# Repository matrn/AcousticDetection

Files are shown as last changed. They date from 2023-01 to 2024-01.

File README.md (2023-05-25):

# System for Acoustic Detection and Localization Based on Two Microphones
# Systém pro akustickou detekci a lokalizaci založený na dvou mikrofonech

This repository contains the source code, schematic, and PCB layout of a demonstration device designed to detect and locate acoustic impulse events. The device is composed of an ESP32 microcontroller and two MEMS microphones SPH0645LM4H.

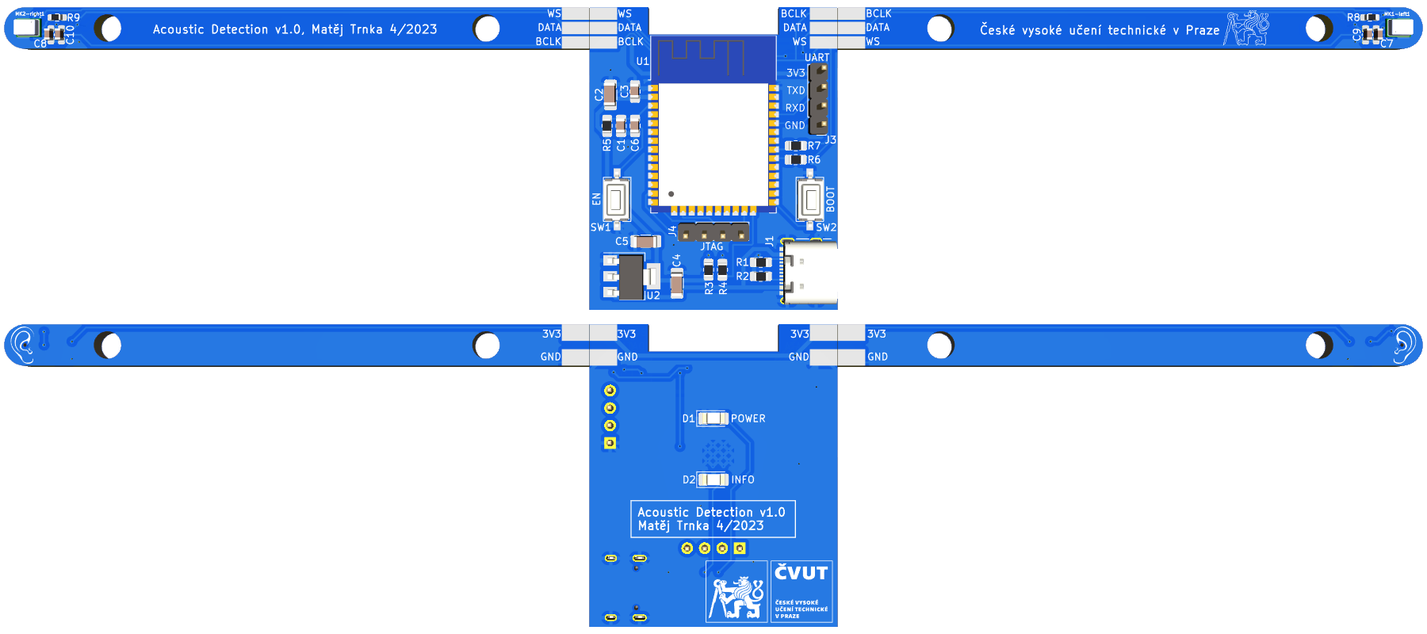
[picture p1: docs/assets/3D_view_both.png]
PCB 3D view

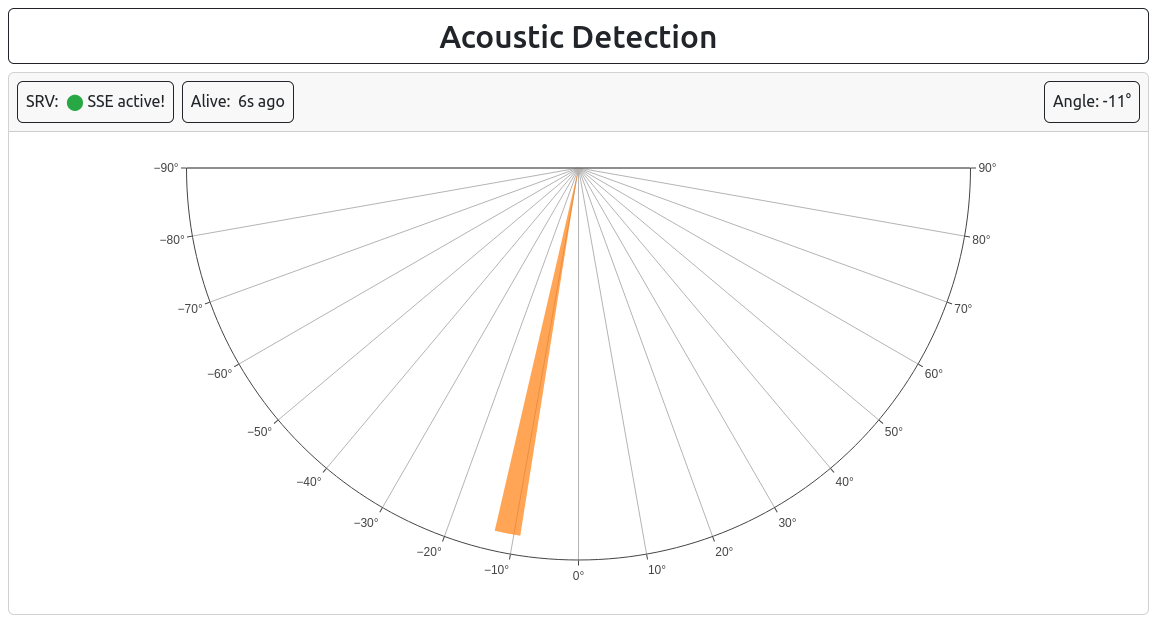
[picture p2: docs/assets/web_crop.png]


## Directories
- `AcousticDetection_HW/` - KiCad schematic & PCB
- `AcousticDetection_SW/` - source code of the ESP32 firmware
- `web` - source code for the ESP32 web page
- `models` - 3D models for 3D printing
- `dsp_toolbox/` - some tools used during development of the signal processing

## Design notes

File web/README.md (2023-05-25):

# ESP32 Web page source code
Script `bundle_all.sh` is automatically called by PlatformIO during FS build.

## Scripts
- python script `bundle.py` takes all files from `src/` dir, if file js Javascript it runs minification and compresses all to the gzip
- bash script `bundle_all.sh` runs `PurgeCSS` to clean unused components from Bootstrap template and then `bundle.py`

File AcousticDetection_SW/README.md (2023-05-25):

# Source code of the AcousticDetection device

The code is written in Arduino framework with the help of PlatformIO platform.

## Code setup
- copy `include/config.hpp.example` to `include/config.hpp` and set required values
- if you want to change distance between microphones, edit `lib/dsp/config.hpp`
- if you want Wi-Fi AP mode instead of station mode, uncomment `#define ENABLE_WIFI_AP` in the `src/main.cpp` file
- to disable OTA (Over the Air) update, comment out `#define ENABLE_OTA`

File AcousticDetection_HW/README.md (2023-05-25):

# KiCad schematic and PCB layout of the AcousticDetection device

PCB 3D view

## Directories
- `lib/` - additional KiCad libraries used for the PCB
- `gerber/` - gerber export ready for production, it containes `single/` version where all three parts are in the same file and `separated/` for three separated gerber files
- `FORMODEL-AcousticDetection_HW/` - copy of this main `AcousticDetection_HW` PCB files, used for the images export into final thesis. Do not use this for production.
- `plots/` - PDF plots of schematic & PCB layout

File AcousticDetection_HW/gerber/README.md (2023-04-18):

# Tutorial
- [https://support.jlcpcb.com/article/194-how-to-generate-gerber-and-drill-files-in-kicad-6](https://support.jlcpcb.com/article/194-how-to-generate-gerber-and-drill-files-in-kicad-6)

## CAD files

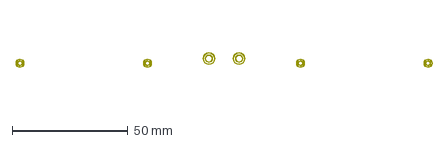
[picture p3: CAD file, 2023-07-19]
models/case/2D.dxf
179.4 x 6.20 mm

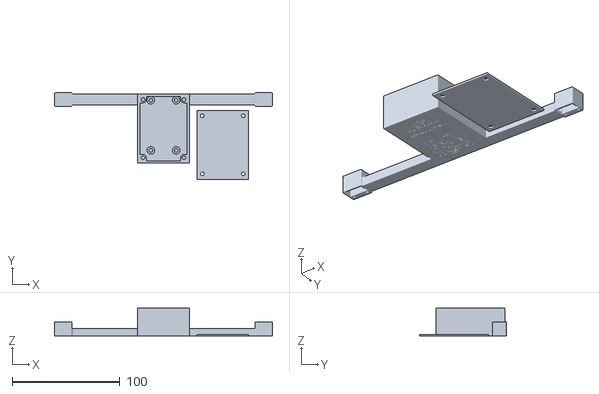
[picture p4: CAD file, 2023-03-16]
models/testing_prototype/AcousticDetectionCase.stl
202.4 x 80.3 x 25.8

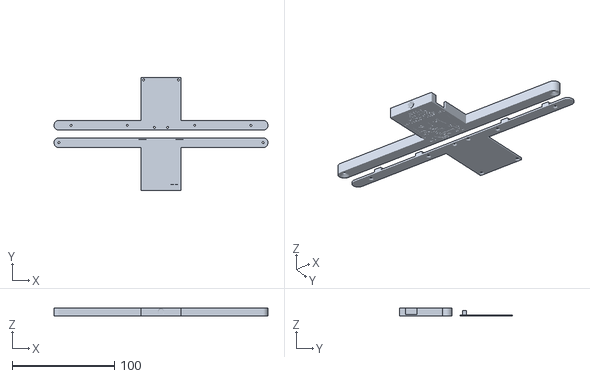
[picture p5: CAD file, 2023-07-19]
models/case/AcousticDetectionCase.stl
209.6 x 111.0 x 7.85

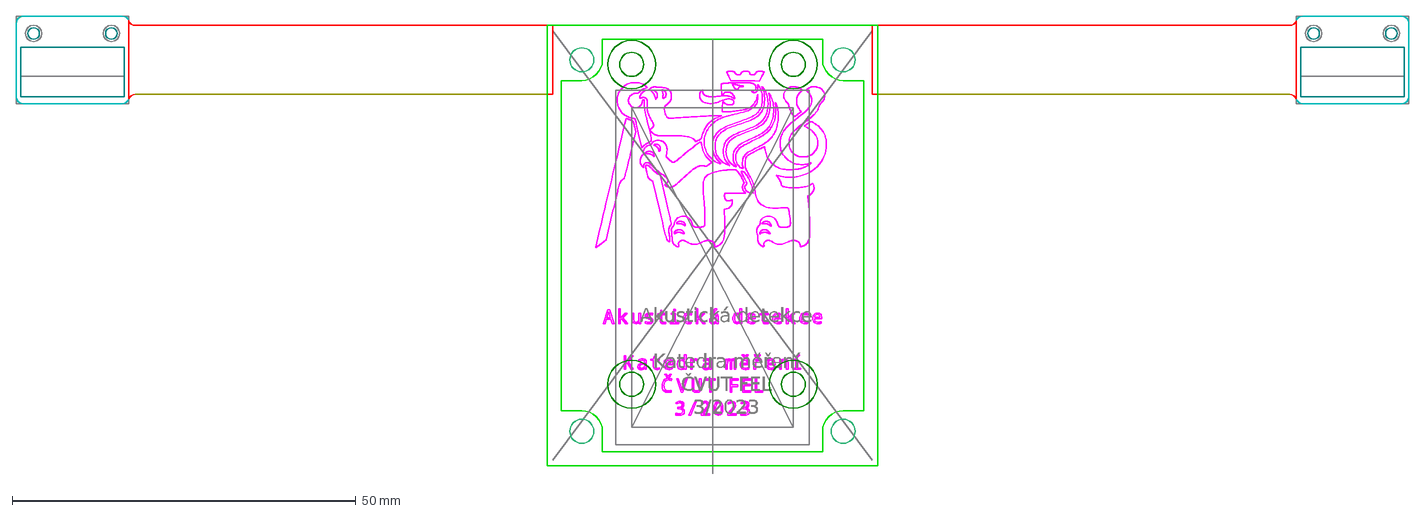
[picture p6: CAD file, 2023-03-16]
models/testing_prototype/2D.dxf
Akustická detekce Katedra měření ČVUT FEL 3/2023

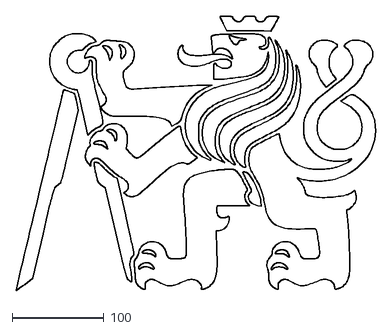
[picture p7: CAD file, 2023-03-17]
models/case/cvut_logo.dxf
393.1 x 299.7

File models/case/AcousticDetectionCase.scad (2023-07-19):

//build = false;
build = true;

$fn = build?200:30;

include <threadlib/threadlib.scad>
UNC_THREAD_SCALE = 1.08;
thread_end_wall_thickness = 0.8;

base_h = 1.6;
logo_h = 0.2;
text_h = 0.2;   //0.4
box_h = 6.25;
arms_h = 4;

solder_pads_h = 1;   // and LEDs

cover_h = 1.2;
cover_pads_h = 4.2;

mic_pos = [100, 19];
mic_hole_r1 = 1;
mic_hole_r2 = 3.6;

cover_holes_h = 1;
cover_holes_r1 = 1;
cover_holes_r2 = 3.9/2;
cover_holes_pos = [
	[88, 19],
	[-88, 19],
	[33, 19],
	[-33, 19],
	[6.5, 21],
	[-6.5, 21],
	[17, -25.5],
	[-17, -25.5]
];


module mic_hole(second=false){
	mp = second?-1:1;
	translate([mp*mic_pos[0], mic_pos[1], base_h/2]) cylinder(base_h, mic_hole_r2, mic_hole_r1, center=true); 
}

module usb_hole(){
	// from bottom 5.5 mm -> from center 16,5 mm
	// from base 3.5
	h = 3.5;
	off = -16.5;
    
	translate([36/2+2/2+1-0.8, off, h]) cube([2, 12, 7], center=true);
}

module box(){
	difference(){
		linear_extrude(box_h) import("2D.dxf", layer="box");
		linear_extrude(box_h+0.1) import("2D.dxf", layer="padded_device");
	}
}

module rotated_tripod_thread(){
	difference(){
		// Most consumer cameras are fitted with 1/4-20 UNC threads (https://en.wikipedia.org/wiki/Tripod_(photography))
		// 20-UN-1/4 = UNC-1/4
		ss = UNC_THREAD_SCALE;
		rotate([90, 0, 0]) scale([ss, ss, ss]) tap("20-UN-1/4", turns=5);
		
		translate([0, 4/2-thread_end_wall_thickness, 0]) cube([10, 4, 10], center = true);
	}
	
}

module box_base(){
difference(){
	union(){	
		difference(){
			linear_extrude(base_h) import("2D.dxf", layer="box");
			translate([0,0,base_h-solder_pads_h]) linear_extrude(solder_pads_h) import("2D.dxf", layer="solder_pads");
			translate([0,0,-0.02]) linear_extrude(logo_h) mirror([1,0,0]) import("2D.dxf", layer="logo");
			translate([0,0,-0.02]) linear_extrude(text_h) mirror([1,0,0]) import("2D.dxf", layer="text");    
		}

		//usb_hole();

		translate([0,0,base_h]){
			difference(){
				box();
				usb_hole();
			}    
			linear_extrude(box_h-0.2) import("2D.dxf", layer="mount");
		}
	}

	translate([0, -22.2, (base_h+box_h)/2]) rotated_tripod_thread();
	mic_hole();
	mic_hole(true);
}
}

module box_cover(){
difference(){
	union(){
		linear_extrude(cover_h) import("2D.dxf", layer="cover");
		translate([0,0,-cover_pads_h]) linear_extrude(cover_pads_h) import("2D.dxf", layer="cover_pads");
	}
	
	for(pos = cover_holes_pos){
		translate(pos) translate([0,0,cover_h-cover_holes_h/2]) cylinder(cover_holes_h, cover_holes_r1, cover_holes_r2, center=true);
	}
}
}

box_base();
//box_cover();

if(build) translate([0, 55, cover_h]) rotate([0,180,180]) box_cover();
else translate([0, 0, base_h+box_h+2]) box_cover();

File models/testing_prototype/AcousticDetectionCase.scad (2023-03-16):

//build = false;
build = true;

$fn = build?200:30;

	

base_h = 0.8;
logo_h = 0.2;
box_h = 25;
esp_h = 10;
mics_h = 12;
mics_cap_h = 0.8;
arms_h = 6;
cover_h = 1.2;

module usb_hole(){
	h = esp_h + 3;
	off = 30.5;
    
	translate([0, off, h]) cube([10, 2, 6], center=true);
}

module cable_hole(){
	l = 171.4;
	d = 4;
	off = 26.8;
	off_z = 2.7;
    translate([0, off, off_z]) rotate([0, 90, 0]) cylinder(h=l, d=d, center = true);
}


difference(){
    linear_extrude(base_h) import("2D.dxf", layer="base");
    translate([0,0,-0.02]) linear_extrude(logo_h) mirror([1,0,0]) import("2D.dxf", layer="logo");
    translate([0,0,-0.05]) linear_extrude(base_h+0.1) import("2D.dxf", layer="mics_holes");
}

//cable_hole();

translate([0,0,base_h]){
    difference()
    {
        linear_extrude(box_h) import("2D.dxf", layer="box");
        usb_hole();
		cable_hole();
    }
    
    linear_extrude(esp_h) import("2D.dxf", layer="esp");
    
    difference(){
        linear_extrude(mics_h) import("2D.dxf", layer="mics_box");
        translate([0,0,-0.05]) linear_extrude(mics_h-mics_cap_h+0.05) import("2D.dxf", layer="mics_holes");
        cable_hole();
    }
    
    difference(){
        linear_extrude(arms_h) import("2D.dxf", layer="arms");
        cable_hole();
    }
}

if(build) translate([55, -15, 0]) linear_extrude(cover_h) import("2D.dxf", layer="cover");
else translate([0, 0, base_h+box_h+2]) linear_extrude(cover_h) import("2D.dxf", layer="cover");

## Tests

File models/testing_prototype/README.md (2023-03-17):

## 3D design problems
- SPH0645 mics (SMD part) collide with design - there should be a small rectangular hole
- ESP32's pin headers are blocked by 2 of 4 cylinders on the back side
- cylinders holes for ESP32 are too big for the M3 screw without a threaded insert
- hole for cables in the arms should be a little bit bigger
- text is not readable - it should be higher and text bigger (size of the CTU logo is fine)

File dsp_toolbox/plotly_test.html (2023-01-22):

## Acoustic Detection

WS: ⬤ WS not loaded Angle: -

Logs

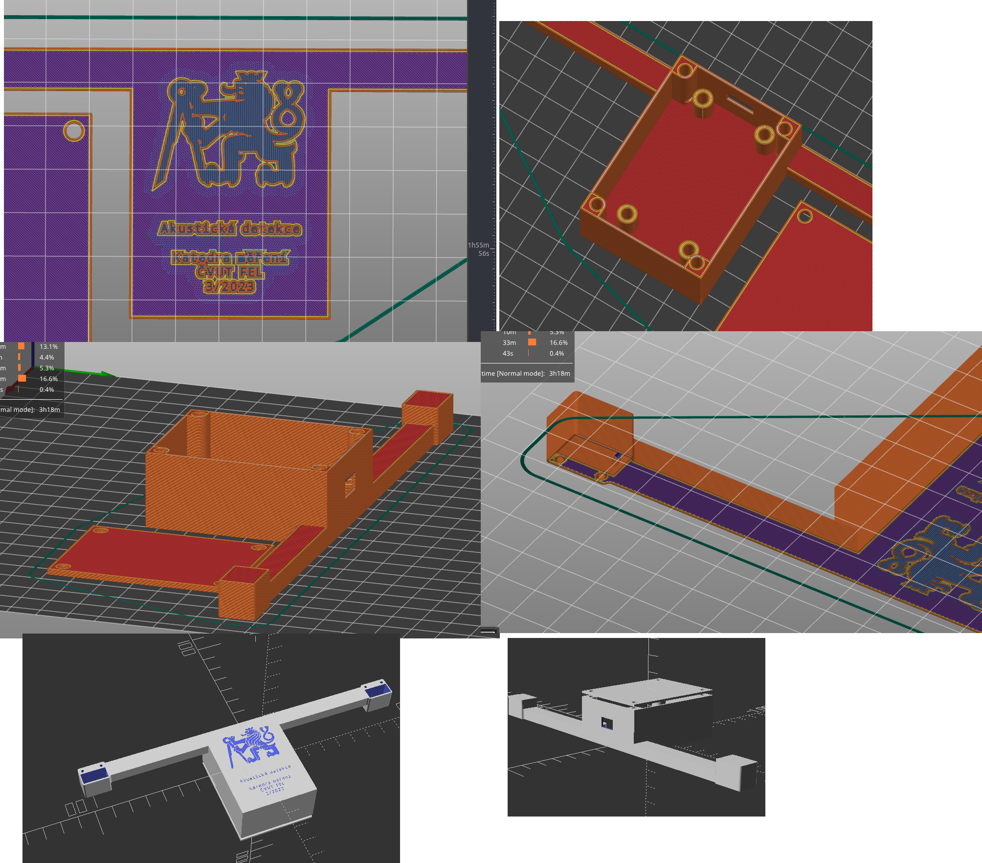
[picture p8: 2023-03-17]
models/testing_prototype/box.png

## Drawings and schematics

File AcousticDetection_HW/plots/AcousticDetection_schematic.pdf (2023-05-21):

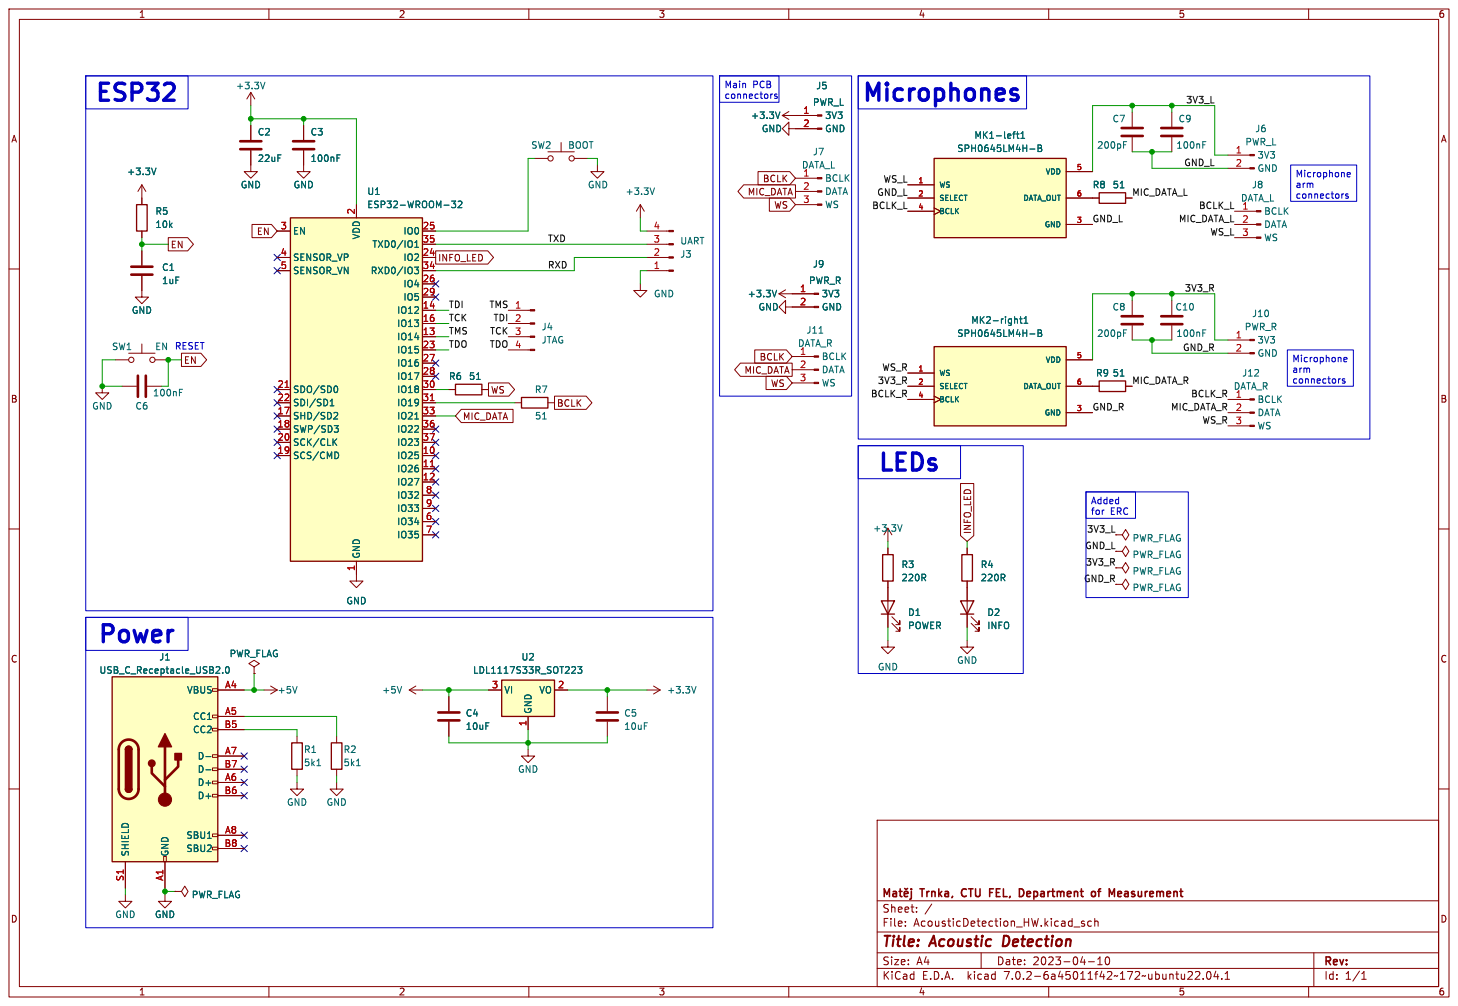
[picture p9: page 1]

2 SCK/CLK 20 SDO/SD0 21 SDI/SD1 22

Id: 1/1 Title: Acoustic Detection

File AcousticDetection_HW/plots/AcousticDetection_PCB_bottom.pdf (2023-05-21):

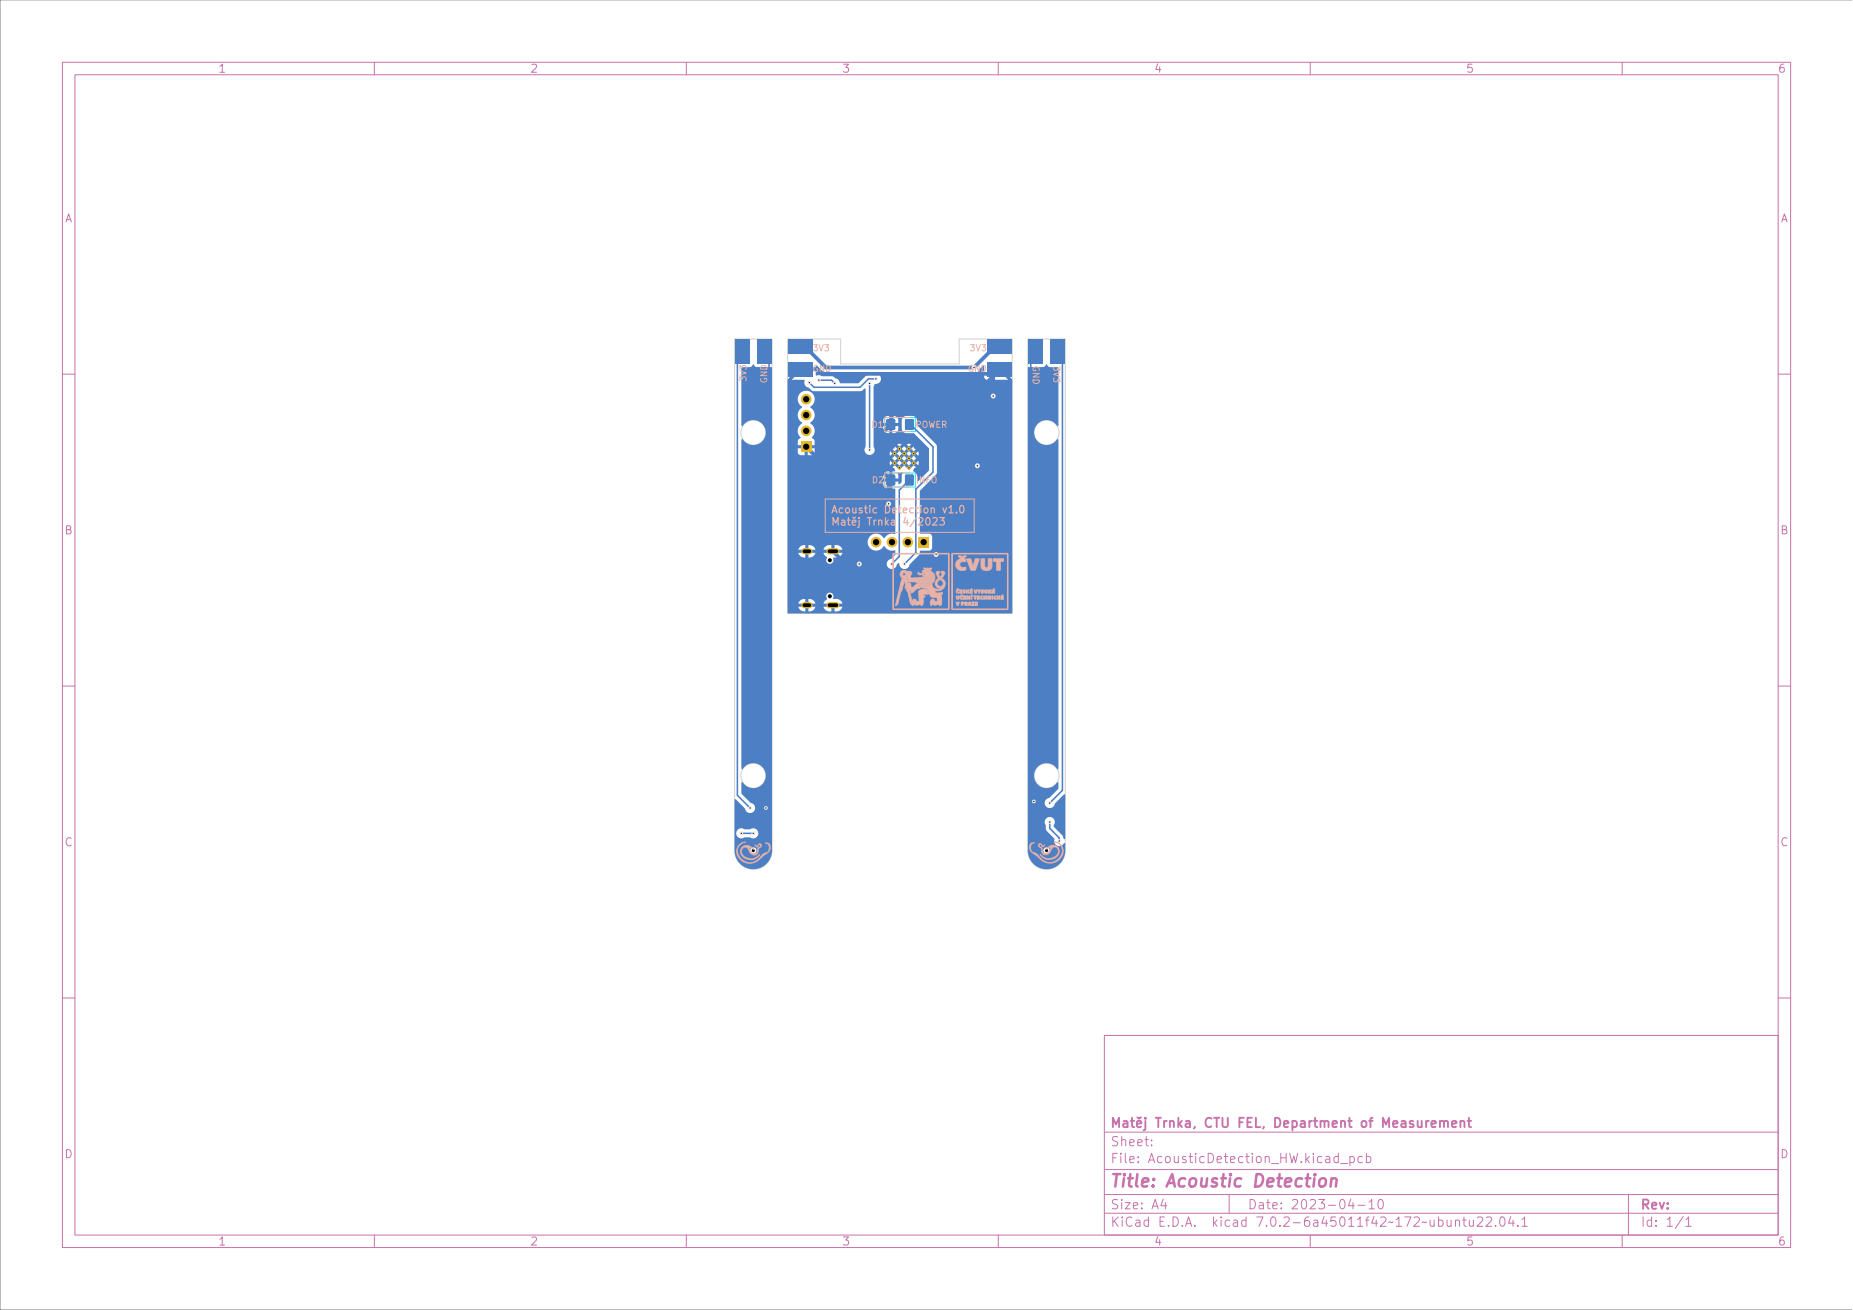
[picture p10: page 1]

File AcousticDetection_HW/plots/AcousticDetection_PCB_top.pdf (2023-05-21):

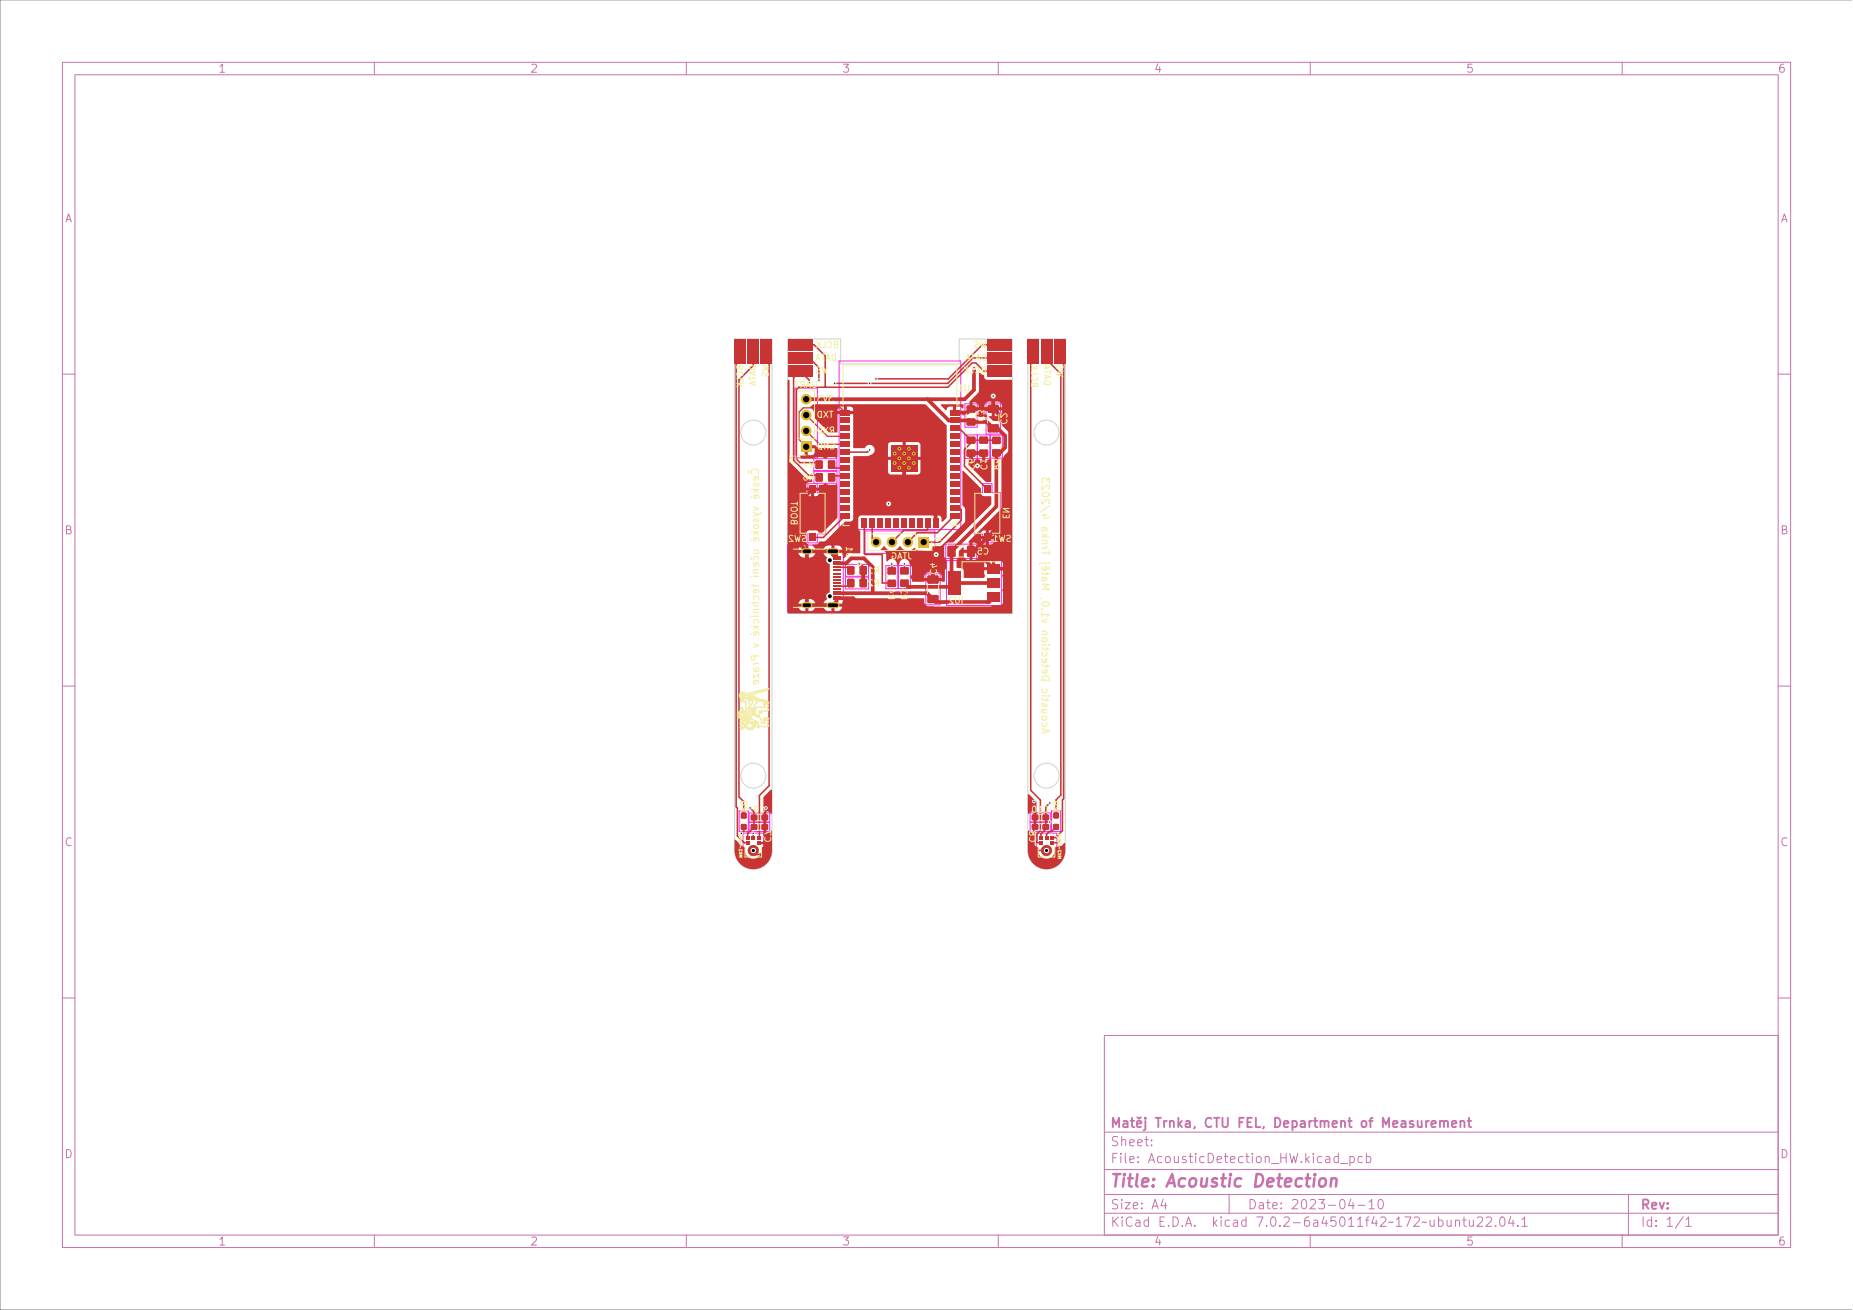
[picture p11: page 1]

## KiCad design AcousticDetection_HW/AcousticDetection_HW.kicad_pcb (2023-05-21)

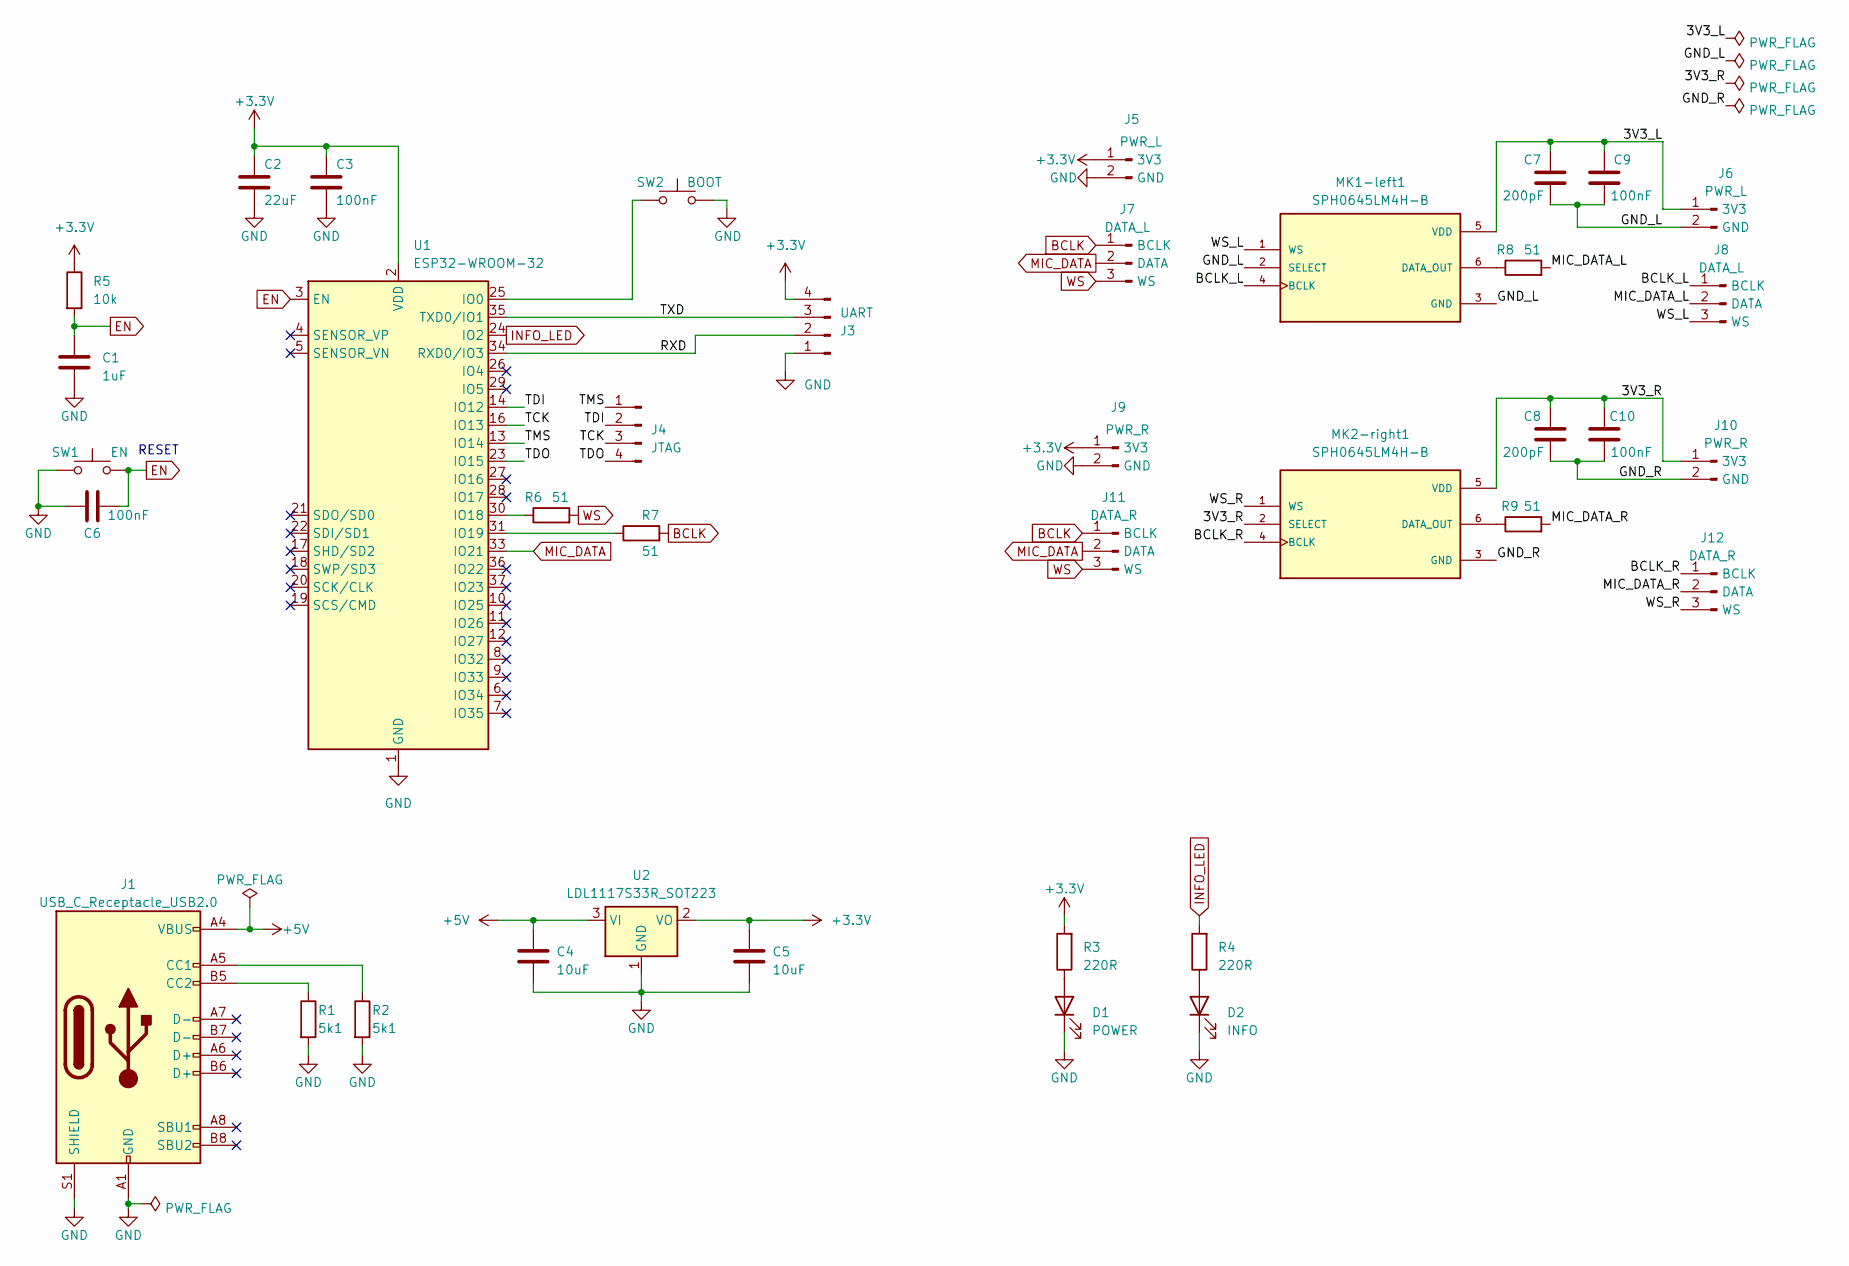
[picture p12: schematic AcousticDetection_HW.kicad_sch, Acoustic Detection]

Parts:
C1: 1uF; C_0805_2012Metric_Pad1.18x1.45mm_HandSolder
C2: 22uF; C_1206_3216Metric_Pad1.33x1.80mm_HandSolder
C3, C6: 100nF; C_0805_2012Metric_Pad1.18x1.45mm_HandSolder
C4, C5: 10uF; C_1206_3216Metric_Pad1.33x1.80mm_HandSolder
C7, C8: 200pF; C_0603_1608Metric_Pad1.08x0.95mm_HandSolder
C9, C10: 100nF; C_0603_1608Metric_Pad1.08x0.95mm_HandSolder
D1: POWER; LED_1206_3216Metric_Pad1.42x1.75mm_HandSolder
D2: INFO; LED_1206_3216Metric_Pad1.42x1.75mm_HandSolder
J1: USB_C_Receptacle_USB2.0; USB_C_Receptacle_GCT_USB4105-xx-A_16P_TopMnt_Horizontal
J3: UART; PinHeader_1x04_P2.54mm_Vertical
J4: JTAG; PinHeader_1x04_P2.54mm_Vertical
J5, J6: PWR_L; PowerConnector
J7, J8: DATA_L; DataConnector
J9, J10: PWR_R; PowerConnector
J11, J12: DATA_R; DataConnector
MK1-left1, MK2-right1: SPH0645LM4H-B; MIC_SPH0645LM4H-B
R1, R2: 5k1; R_0805_2012Metric_Pad1.20x1.40mm_HandSolder
R3, R4: 220R; R_0805_2012Metric_Pad1.20x1.40mm_HandSolder
R5: 10k; R_0805_2012Metric_Pad1.20x1.40mm_HandSolder
R6, R7: 51; R_0805_2012Metric_Pad1.20x1.40mm_HandSolder
R8, R9: 51; R_0603_1608Metric_Pad0.98x0.95mm_HandSolder
SW1: EN; SW_Tactile_SPST_NO_Straight_CK_PTS636Sx25SMTRLFS
SW2: BOOT; SW_Tactile_SPST_NO_Straight_CK_PTS636Sx25SMTRLFS
U1: ESP32-WROOM-32
U2: LDL1117S33R_SOT223; SOT-223-3_TabPin2

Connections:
+3.3V: C2.2, C3.2, C5.1, J3.4, J5.1 (3V3), J9.1 (3V3), R3.2, R5.1, U1.2 (VDD), U2.2 (VO)
+5V: C4.1, J1.A4 (VBUS), J1.A9 (VBUS), J1.B4 (VBUS), J1.B9 (VBUS), U2.3 (VI)
/3V3_L: C7.2, C9.2, J6.1 (3V3), MK1-left1.5 (VDD)
/3V3_R: C8.2, C10.2, J10.1 (3V3), MK2-right1.2 (SELECT), MK2-right1.5 (VDD)
/BCLK_L: J8.1 (BCLK), MK1-left1.4 (BCLK)
/BCLK_R: J12.1 (BCLK), MK2-right1.4 (BCLK)
/GND_L: C7.1, C9.1, J6.2 (GND), MK1-left1.2 (SELECT), MK1-left1.3 (GND)
/GND_R: C8.1, C10.1, J10.2 (GND), MK2-right1.3 (GND)
/MIC_DATA_L: J8.2 (DATA), R8.2
/MIC_DATA_R: J12.2 (DATA), R9.2
/RXD: J3.2, U1.34 (RXD0/IO3)
/TCK: J4.3, U1.16 (IO13)
/TDI: J4.2, U1.14 (IO12)
/TDO: J4.4, U1.23 (IO15)
/TMS: J4.1, U1.13 (IO14)
/TXD: J3.3, U1.35 (TXD0/IO1)
/WS_L: J8.3 (WS), MK1-left1.1 (WS)
/WS_R: J12.3 (WS), MK2-right1.1 (WS)
BCLK: J7.1 (BCLK), J11.1 (BCLK), R7.2
EN: C1.2, C6.2, R5.2, SW1.2, U1.3 (EN)
GND: C1.1, C2.1, C3.1, C4.2, C5.2, C6.1, D1.1 (K), D2.1 (K), J1.A1 (GND), J1.A12 (GND), J1.B1 (GND), J1.B12 (GND), J1.S1 (SHIELD), J3.1, J5.2 (GND), J9.2 (GND), R1.2, R2.2, SW1.1, SW2.2, U1.1 (GND), U1.15 (GND), U1.38 (GND), U1.39 (GND), U2.1 (GND)
INFO_LED: R4.2, U1.24 (IO2)
MIC_DATA: J7.2 (DATA), J11.2 (DATA), U1.33 (IO21)
unnamed: D1.2 (A), R3.1
unnamed: D2.2 (A), R4.1
unnamed: J1.A5 (CC1), R2.1
unnamed: J1.B5 (CC2), R1.1
unnamed: MK1-left1.6 (DATA_OUT), R8.1
unnamed: MK2-right1.6 (DATA_OUT), R9.1
unnamed: SW2.1, U1.25 (IO0)
unnamed: R6.1, U1.30 (IO18)
unnamed: R7.1, U1.31 (IO19)
WS: J7.3 (WS), J11.3 (WS), R6.2

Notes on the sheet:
RESET

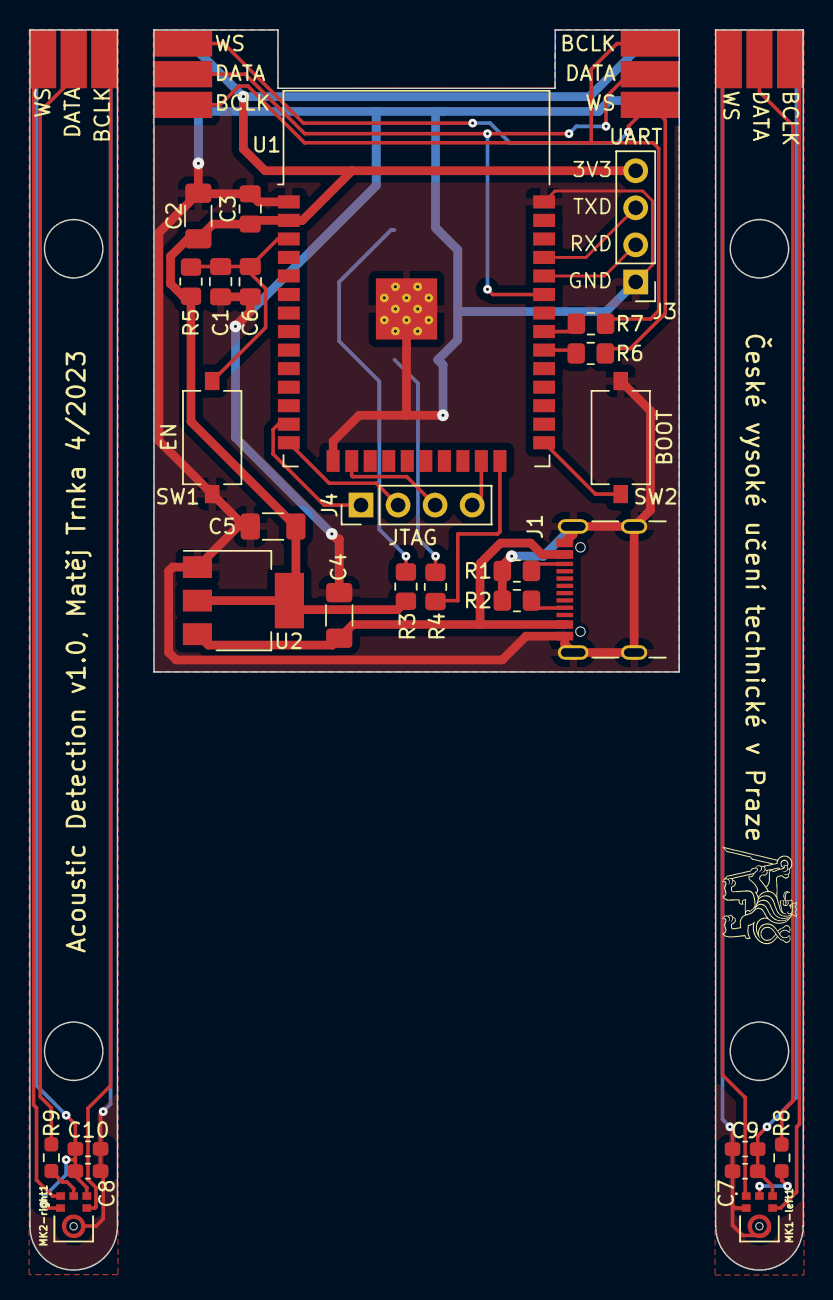
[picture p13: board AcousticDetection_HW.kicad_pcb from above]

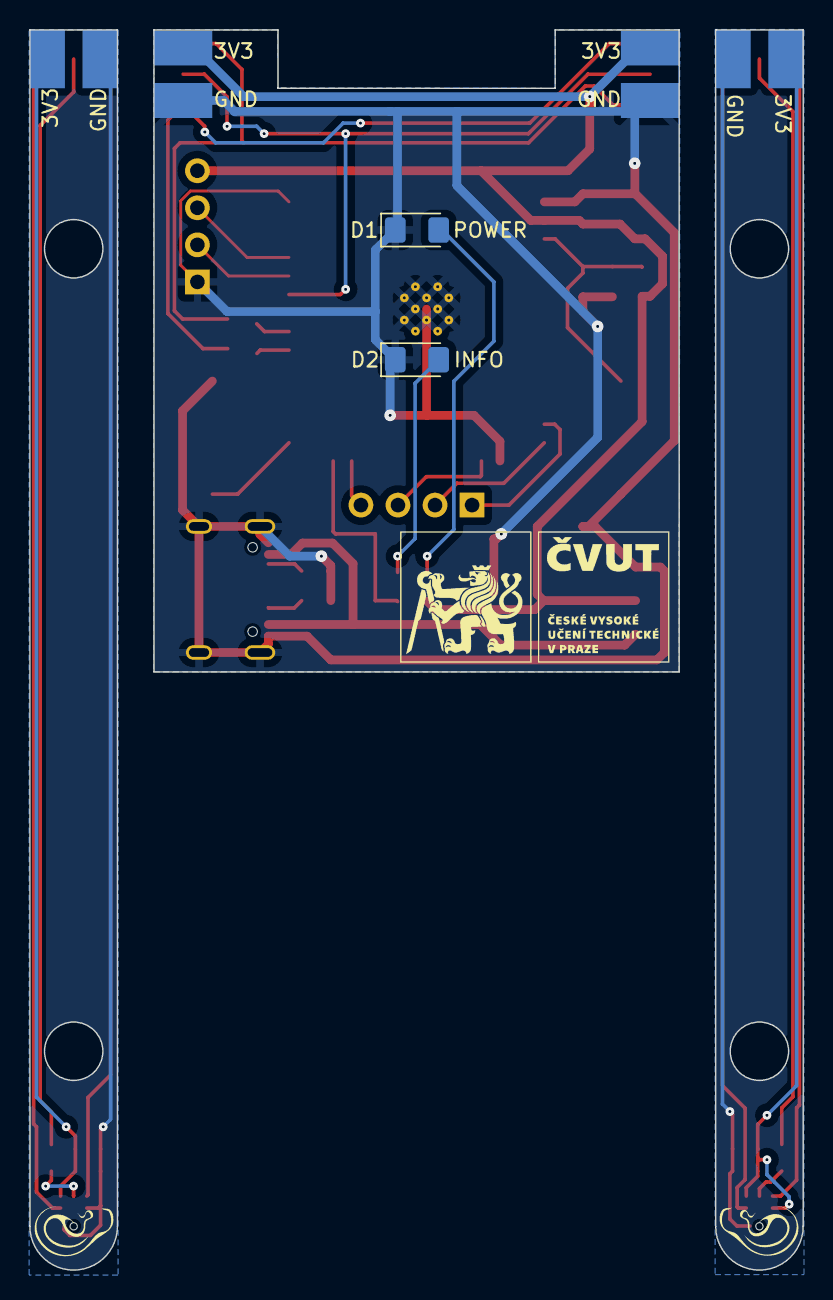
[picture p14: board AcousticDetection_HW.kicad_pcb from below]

Board: 2 copper layers, 53.0 x 85.0 mm, 38 parts (6 on the bottom side), 33 nets.

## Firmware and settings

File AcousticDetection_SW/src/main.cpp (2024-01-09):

#include <Arduino.h>
#include <AsyncTCP.h>
#include <EEPROM.h>
#include <ESPAsyncWebServer.h>
#include <ESPmDNS.h>
#include <FS.h>
#include <SPIFFS.h>
#include <SPIFFSEditor.h>
#include <WiFi.h>

#include "../include/circular_buffer.hpp"
#include "../include/config.hpp"
#include "../lib/dsp/dsp.hpp"
#include "../lib/i2s_mic/mic.hpp"


// ---------- SETTINGS ---------- //
// #define ENABLE_WS    // WebSockets
#define ENABLE_SSE	// Server Sent Events
// #define ENABLE_SSE_CORS_HEADER   // used when you want to request server from different url (for example if you open index.html file in your browser)

#define ENABLE_WIFI_AP	// WIFI_STA otherwise
/* settings bellow are not recommended because it cause performance problems */
// #define ENABLE_WIFI_AP_404_REDIRECT
// #define ENABLE_WIFI_AP_DNS
// #define ENABLE_WIFI_AP_CAPTIVE_PORTAL   // not recommended

#define ENABLE_OTA

// #define AUDIO_CAPTURE_SERVER_ENABLED   // if enabled, ESP32 sends audio samples to the server specified in AUDIO_CAPTURE_SERVER_URL via HTTP
// ------------------------------ //
#define LAST_CAPTURE_TIME_THRESHOLD 100	// 100ms - minimal delay between acoustic event detections - it's used to prevent detection of sound reflections (echo supression)



#ifdef AUDIO_CAPTURE_SERVER_ENABLED
	// The problem is that parts of the audio stream are missing, probably because of the too long data sending process
	#define AUDIO_CAPTURE_SERVER_URL "http://192.168.0.100:5005/i2s_samples"  //"http://192.168.26.92:5005/i2s_samples"
	// #define AUDIO_CAPTURE_SERVER_URL "http://10.42.0.1:5005/i2s_samples"
	#define SAMPLES_PER_REQ 1024 * 50
	#include <HTTPClient.h>
	WiFiClient wifiClient;
	HTTPClient httpClient;
	uint8_t *data_for_send;
#endif


#ifdef ENABLE_WIFI_AP
	#include <DNSServer.h>
	DNSServer dnsServer;
	const IPAddress AP_local_ip(192, 168, 1, 1);
	const IPAddress AP_gateway(192, 168, 1, 1);
	const IPAddress AP_subnet(255, 255, 255, 0);

	#ifdef ENABLE_WIFI_AP_CAPTIVE_PORTAL
		class CaptiveRequestHandler : public AsyncWebHandler {
		public:
			CaptiveRequestHandler() {}
			virtual ~CaptiveRequestHandler() {}

			bool canHandle(AsyncWebServerRequest *request) {
				// request->addInterestingHeader("ANY");
				return true;
			}

			void handleRequest(AsyncWebServerRequest *request) {
				Serial.printf("Client was trying to reach: http://%s%s\n", request->host().c_str(), request->url().c_str());
				AsyncWebServerResponse *response = request->beginResponse(302);
				response->addHeader("Location", "http://" + WiFi.softAPIP().toString());
				return request->send(response);
			}
		};
	#endif
#endif

#ifdef ENABLE_OTA
	#include <ArduinoOTA.h>
#endif


#define CORR_SIZE correlation_window_samples_num
CircularBuffer<audio_sample_t, CORR_SIZE> x1;
CircularBuffer<audio_sample_t, CORR_SIZE> x2;

LRMics mics(I2S_NUM_0);

TaskHandle_t dsp_task;
DSP dsp;

OnsetDetector od1;
OnsetDetector od2;



AsyncWebServer server(80);
#ifdef ENABLE_WS
	AsyncWebSocket ws("/ws");
#endif
#ifdef ENABLE_SSE
	AsyncEventSource events("/events");
	#define SSE_SEND_ALIVE_MSG_TIME 8 * 1000  // 8 seconds
	unsigned long last_sse_alive_msg_time = 0;

	void sse_send_alive_msg() {
		events.send(String(millis()).c_str(), "alive");
	}
#endif



void send_angle(int angle, int error) {
	/*
		@angle - angle in range [0, 180]
		@error - uncertainty of angle in range [0, 10] - on web, width will be width=2*error
	*/
	char str[12];
	sprintf(str, "%d;%d", angle, error);
	#ifdef ENABLE_WS
		ws.textAll(str);
	#endif
	#ifdef ENABLE_SSE
		events.send(str, "angle");
	#endif
}

void dsp_func(void *param) {
	Serial.printf("DSP running on core: %d\n", xPortGetCoreID());
	LRMics *sampler = (LRMics *)(param);

	#ifndef AUDIO_CAPTURE_SERVER_ENABLED
		int capture_number_of_samples = 0;
		bool capture_started = false;

		unsigned long last_capture = 0;
	#endif

	while (true) {
		// mics.read_and_print();
		// continue;

		#ifdef AUDIO_CAPTURE_SERVER_ENABLED
			int sampled = 0;
			int ppp = 0;
			while (sampled < SAMPLES_PER_REQ) {
				int count = sampler->read(true);  //[](audio_sample_t left, audio_sample_t right){

				Serial.printf("%d, %d\n", count, sampled);
				// Serial.println("-------LEFT-------");
				// for(int i = 0; i < count; i ++) Serial.printf("%d,", sampler->left_channel_data[i]);
				// Serial.println("------------------");

				// Serial.println("-------RIGHT-------");
				// for(int i = 0; i < count; i ++) Serial.printf("%d,", sampler->right_channel_data[i]);
				// Serial.println("-------------------");

				memcpy(data_for_send + sampled * sizeof(int16_t), sampler->data, count * sizeof(int16_t));
				sampled += count;

				if (ppp == 5) httpClient.begin(wifiClient, AUDIO_CAPTURE_SERVER_URL);
				if (ppp == 6) httpClient.addHeader("content-type", "application/octet-stream");
				ppp++;
			}

			digitalWrite(LED_BUILTIN, HIGH);
			httpClient.POST(data_for_send, sampled * sizeof(int16_t));
			httpClient.end();
			digitalWrite(LED_BUILTIN, LOW);
			// free(data);
		#else

			int count = sampler->read();  //[](audio_sample_t left, audio_sample_t right){

			for (int i = 0; i < count; i++) {
				audio_sample_t left = sampler->data[i];
				audio_sample_t right = sampler->data[++i];

				// OnSet detection with acoustic echo supression using time delay 100ms (LAST_CAPTURE_TIME_THRESHOLD)
				if (od1.detect(left) && od2.detect(right) && capture_started == false && millis() - last_capture > LAST_CAPTURE_TIME_THRESHOLD) {
					Serial.println("Capture started");
					capture_started = true;
				}

				if (capture_started) {
					/*
						Capture is currently implemented using Circular Buffer because it was used in the past but normal array would be little bit more efficient
					*/
					x1.push(left);
					x2.push(right);
				}

				if (capture_started && ++capture_number_of_samples >= CORR_SIZE) {
					// audio samples capture process is done
					Serial.println("START PROCESSING");
					capture_started = false;
					capture_number_of_samples = 0;
					last_capture = millis();

					xcorr_result_t xcorr_peak;
					bool xcorr_peak_found = dsp.xcorr_max<CircularBuffer<audio_sample_t, CORR_SIZE> >(x1, x2, xcorr_peak, CORR_SIZE, max_shift_samples_num + 1, true, true, true);

					if (xcorr_peak_found) {
						digitalWrite(LED_BUILTIN, HIGH);
						int Nshift = xcorr_peak.max_pos;

						if (xcorr_peak.interpolated_max_pos > Nshift + 1 || xcorr_peak.interpolated_max_pos < Nshift - 1) {
							// this should never happen but added just to be sure
							Serial.printf("ERROR: interpolation %f is outside of %d+(-1,1) range", xcorr_peak.interpolated_max_pos, Nshift);
							xcorr_peak.interpolated_max_pos = Nshift;
						}

						double tau = xcorr_peak.interpolated_max_pos * (1. / I2S_SAMPLE_RATE);
						if (-maxN <= Nshift && Nshift <= maxN) {
							// we use interpolated max_pos for angle calculation and normal for error calculation
							int angle = dsp.rad2deg(dsp.theta_from_tau(tau)) + 0.5;
							int error = dsp.rad2deg(dsp.theta_error(Nshift)) + 0.5;

							Serial.printf("Before interpolation: %d, after: %f\n", xcorr_peak.max_pos, xcorr_peak.interpolated_max_pos);
							Serial.printf("N: %d, max: %f, tau: %f s, angle: %d +- %d\n", Nshift, xcorr_peak.max_Rx, tau, angle, error);

							send_angle(angle, error);
						} else {
							// we ignore peaks outside of Nmax interval, CCF is computed on the interval [-Nmax-1, Nmax+1] to save operations
							Serial.printf("XCORR - shift too big: N: %d, max: %f, tau: %f s\n", Nshift, xcorr_peak.max_Rx, tau);
						}
						digitalWrite(LED_BUILTIN, LOW);
					}
				}
			}
		#endif
	}
}

#ifdef ENABLE_WS
	void onWsEvent(AsyncWebSocket *server, AsyncWebSocketClient *client, AwsEventType type, void *arg, uint8_t *data, size_t len) {
		if (type == WS_EVT_CONNECT) {
			Serial.printf("ws[%s][%u] connect\n", server->url(), client->id());
			client->printf("Hello Client %u :)", client->id());
			client->ping();
		} else if (type == WS_EVT_DISCONNECT) {
			Serial.printf("ws[%s][%u] disconnect\n", server->url(), client->id());
		} else if (type == WS_EVT_ERROR) {
			Serial.printf("ws[%s][%u] error(%u): %s\n", server->url(), client->id(), *((uint16_t *)arg), (char *)data);
		} else if (type == WS_EVT_PONG) {
			Serial.printf("ws[%s][%u] pong[%u]: %s\n", server->url(), client->id(), len, (len) ? (char *)data : "");
		} else if (type == WS_EVT_DATA) {
		}
	}
#endif


#define ENABLE_EEPROM_THRESHOLD

#ifdef ENABLE_EEPROM_THRESHOLD
	#define EEPROM_SIZE 2

	union uint16_t_conv {
		char b[2];
		uint16_t val;
	};
	uint16_t get_OD_threshold_from_EEPROM() {
		union uint16_t_conv data;
		data.b[0] = EEPROM.read(0);
		data.b[1] = EEPROM.read(1);
		return data.val;
	}

	void set_OD_threshold_to_EEPROM(uint16_t val) {
		od1.set_threshold(val);
		od2.set_threshold(val);

		union uint16_t_conv data;
		data.val = val;
		EEPROM.write(0, data.b[0]);
		EEPROM.write(1, data.b[1]);
		EEPROM.commit();
	}
#endif


void setup() {
	pinMode(LED_BUILTIN, OUTPUT);
	digitalWrite(LED_BUILTIN, HIGH);
	Serial.begin(115200);

	#ifdef ENABLE_EEPROM_THRESHOLD
		EEPROM.begin(EEPROM_SIZE);
		uint16_t OD_threshold = get_OD_threshold_from_EEPROM();
		if(OD_threshold < std::numeric_limits<std::uint16_t>::max()){
			od1.set_threshold(OD_threshold);
			od2.set_threshold(OD_threshold);
		}
	#endif
	
	#ifndef RELEASE
		Serial.setDebugOutput(true);
	#endif
	Serial.print(F("START, file: " __FILE__ " built on " __DATE__ " " __TIME__));
	#ifdef RELEASE
		Serial.println(" - RELEASE version");
	#else
		Serial.println(" - DEBUG version");
	#endif

	Serial.println("-----------------------------");
	Serial.println("ESP32 Acoustic Detection v1.0");
	Serial.println("-----------------------------");

	Serial.printf("xcorr window size: %d\n", CORR_SIZE);
	Serial.printf("fs: %d, mics d: %f, max N: %d\n", I2S_SAMPLE_RATE, MICS_DISTANCE, maxN);
	Serial.printf("setup running on core: %d\n", xPortGetCoreID());
	mics.init();

	#ifdef AUDIO_CAPTURE_SERVER_ENABLED
		data_for_send = (uint8_t *)malloc(SAMPLES_PER_REQ * sizeof(int16_t));
	#endif

	// Serial.println(ESP.getFreeHeap());
	// for(int i = 0; i < 2; i ++){
	// 	data_for_send.push((uint8_t*)malloc(SAMPLES_PER_REQ*sizeof(int16_t)));
	// }
	// Serial.println(ESP.getFreeHeap());
	// auto start = micros();
	// for(int i = 0; i < 100; i ++){
	// 	correlation(x1, x2, CORR_SIZE, max_shift_samples_num);
	// }
	// auto end = micros();
	// Serial.printf("Correlation time: %f us\n", (end-start)/100.);
	// while(1);
	/* Core where the task should run */

	#ifdef ENABLE_WIFI_AP
		// docs: https://espressif-docs.readthedocs-hosted.com/projects/arduino-esp32/en/latest/api/wifi.html
		Serial.println("---------- AP mode ----------");
		Serial.println(String("AP creation: ") + (WiFi.softAP(wifi_ap_ssid, wifi_ap_pass, 6, 0, 4) ? "true" : "false"));
		Serial.println(String("AP config: ") + (WiFi.softAPConfig(AP_local_ip, AP_gateway, AP_subnet) ? "true" : "false"));
		Serial.println("-----------------------------");
	#else
		Serial.println("---------- STA mode ----------");
		Serial.printf("Connecting to: %s\n", wifi_ssid);
		WiFi.mode(WIFI_STA);
		WiFi.begin(wifi_ssid, wifi_password);
		for (int i = 0; i < 3; i++) {
			if (WiFi.waitForConnectResult() == WL_CONNECTED) break;
			Serial.print(".");
		}
		if (WiFi.waitForConnectResult() != WL_CONNECTED) {
			Serial.println("Connection Failed! Rebooting...");
			delay(1000);
			ESP.restart();
		}
		WiFi.hostname(hostname);
		Serial.printf("Connected, ip: %s\n", WiFi.localIP().toString().c_str());

		MDNS.addService("http", "tcp", 80);
		Serial.println("------------------------------");
	#endif

	#ifdef ENABLE_OTA
		// Send OTA events to the browser
		ArduinoOTA.onStart([]() { events.send("Update Start", "ota"); });
		ArduinoOTA.onEnd([]() { events.send("Update End", "ota"); });
		ArduinoOTA.onProgress([](unsigned int progress, unsigned int total) {
			#ifdef ENABLE_SSE
				// send OTA update progress via SSE
				char p[32];
				sprintf(p, "Progress: %u%%\n", (progress / (total / 100)));
				events.send(p, "ota");
			#endif
		});
		ArduinoOTA.onError([](ota_error_t error) {
			#ifdef ENABLE_SSE
				if (error == OTA_AUTH_ERROR)
					events.send("Auth Failed", "ota");
				else if (error == OTA_BEGIN_ERROR)
					events.send("Begin Failed", "ota");
				else if (error == OTA_CONNECT_ERROR)
					events.send("Connect Failed", "ota");
				else if (error == OTA_RECEIVE_ERROR)
					events.send("Recieve Failed", "ota");
				else if (error == OTA_END_ERROR)
					events.send("End Failed", "ota");
			#endif
		});
		// Port defaults to 3232
		// ArduinoOTA.setPort(ota_port);

		// Hostname defaults to esp3232-[MAC]
		ArduinoOTA.setHostname(hostname);

		// No authentication by default
		ArduinoOTA.setPassword(ota_password);

		ArduinoOTA.begin();
	#endif

	SPIFFS.begin();

	server.on("/heap", HTTP_GET, [](AsyncWebServerRequest *request) {
		request->send(200, "text/plain", String(ESP.getFreeHeap()));
	});

	server.on("/get_threshold", HTTP_GET, [](AsyncWebServerRequest *request) {
		request->send(200, "text/plain", "od1=" + String(od1.get_threshold()) + ", od2=" + String(od2.get_threshold())
		#ifdef ENABLE_EEPROM_THRESHOLD
			+ ", EEPROM=" + String(get_OD_threshold_from_EEPROM())
		#endif
		);
	});

	#ifdef ENABLE_EEPROM_THRESHOLD
	server.on("/set_threshold", HTTP_POST, [](AsyncWebServerRequest *request) {
		// format is th=uint16_t-number
		// use: curl -X POST http://192.168.1.1/set_threshold -d "th=4700"
		if (request->params() == 1) {
			AsyncWebParameter *p = request->getParam(0);
			if (p->isPost() && p->name() == String("th")) {
				set_OD_threshold_to_EEPROM(p->value().toInt());
				request->send(200, "text/plain", "OK: " + String(get_OD_threshold_from_EEPROM()));
			} else
				request->send(400, "text/plain", "bad request, use th=value, passed var:" + p->name());
		}
		request->send(400, "text/plain", "bad request, number of params is not eq to 1, use th=value");
	});
	#endif

	// serverStatic supports gzip automatically
	// for GMT date us bash command: LC_TIME=en_US.utf8 TZ=GMT date
	server.serveStatic("/", SPIFFS, "/").setDefaultFile("index.html").setLastModified("Tue May 23 11:30:37 AM GMT 2023");  //.setCacheControl("max-age=600");   // Cache responses for 10 minutes (600 seconds)

	server.onNotFound([](AsyncWebServerRequest *request) {
		#ifndef RELEASE
			Serial.printf("NOT_FOUND: ");
			if (request->method() == HTTP_GET)
				Serial.printf("GET");
			else if (request->method() == HTTP_POST)
				Serial.printf("POST");
			else if (request->method() == HTTP_DELETE)
				Serial.printf("DELETE");
			else if (request->method() == HTTP_PUT)
				Serial.printf("PUT");
			else if (request->method() == HTTP_PATCH)
				Serial.printf("PATCH");
			else if (request->method() == HTTP_HEAD)
				Serial.printf("HEAD");
			else if (request->method() == HTTP_OPTIONS)
				Serial.printf("OPTIONS");
			else
				Serial.printf("UNKNOWN");
			Serial.printf(" http://%s%s\n", request->host().c_str(), request->url().c_str());

			if (request->contentLength()) {
				Serial.printf("_CONTENT_TYPE: %s\n", request->contentType().c_str());
				Serial.printf("_CONTENT_LENGTH: %u\n", request->contentLength());
			}

			int headers = request->headers();
			int i;
			for (i = 0; i < headers; i++) {
				AsyncWebHeader *h = request->getHeader(i);
				Serial.printf("_HEADER[%s]: %s\n", h->name().c_str(), h->value().c_str());
			}

			int params = request->params();
			for (i = 0; i < params; i++) {
				AsyncWebParameter *p = request->getParam(i);
				if (p->isFile()) {
					Serial.printf("_FILE[%s]: %s, size: %u\n", p->name().c_str(), p->value().c_str(), p->size());
				} else if (p->isPost()) {
					Serial.printf("_POST[%s]: %s\n", p->name().c_str(), p->value().c_str());
				} else {
					Serial.printf("_GET[%s]: %s\n", p->name().c_str(), p->value().c_str());
				}
			}
		#endif

		#ifdef ENABLE_WIFI_AP
		#ifdef ENABLE_WIFI_AP_404_REDIRECT
				if (request->getHeader("host")->value() != WiFi.softAPIP().toString()) {
					Serial.printf("Wrong host http://%s%s\n, redirecting\n", request->host().c_str(), request->url().c_str());
					request->redirect("http://" + WiFi.softAPIP().toString());
				} else {
					request->send(404, "text/plain", "404 Not Found");
				}
		#else
				request->send(404, "text/plain", "404 Not Found");
		#endif
		#else
				request->send(404, "text/plain", "404 Not Found");
		#endif
	});

	#ifdef ENABLE_WS
		ws.onEvent(onWsEvent);
		server.addHandler(&ws);
	#endif

	#ifdef ENABLE_SSE
		#ifdef ENABLE_SSE_CORS_HEADER
			DefaultHeaders::Instance().addHeader("Access-Control-Allow-Origin", "*");
		#endif
		events.onConnect([](AsyncEventSourceClient *client) {
			sse_send_alive_msg();
		});
		server.addHandler(&events);
	#endif

	#ifdef ENABLE_WIFI_AP
		#ifdef ENABLE_WIFI_AP_DNS
			dnsServer.setErrorReplyCode(DNSReplyCode::NoError);
			dnsServer.start(53, "*", WiFi.softAPIP());	// redirect to ESP
		#endif
		#ifdef ENABLE_WIFI_AP_CAPTIVE_PORTAL
			server.addHandler(new CaptiveRequestHandler()).setFilter(ON_AP_FILTER);	 // only when requested from AP
		#endif
	#endif

	server.begin();

	Serial.println("Setup done, starting DSP...");
	xTaskCreatePinnedToCore(
		dsp_func,  /* Function to implement the task */
		"DSP",	   /* Name of the task */
		10000,	   /* Stack size in words */
		&mics,	   /* Task input parameter */
		2,		   /* Priority of the task */
		&dsp_task, /* Task handle. */
		1
	);
	Serial.println("Done!");
	digitalWrite(LED_BUILTIN, LOW);
}

void loop() {
	#ifdef ENABLE_WS
		ws.cleanupClients();
	#endif

	#ifdef ENABLE_OTA
		ArduinoOTA.handle();
	#endif

	#ifdef ENABLE_SSE
		if (millis() - last_sse_alive_msg_time > SSE_SEND_ALIVE_MSG_TIME || millis() < last_sse_alive_msg_time) {
			last_sse_alive_msg_time = millis();
			sse_send_alive_msg();
		}
	#endif

	#ifdef ENABLE_WIFI_AP
	#ifdef ENABLE_WIFI_AP_DNS
		dnsServer.processNextRequest();
	#endif
	#endif
}

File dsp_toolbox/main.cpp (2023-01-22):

#include <cassert>
#include <iostream>
#include <sciplot/sciplot.hpp>
#include <vector>

#include "../AcousticDetection_SW/lib/dsp/dsp.hpp"
#include "src/include/sampler.hpp"



// #define START 177923
// #define END 178159
// #define START 178300
// #define END 178700
// #define START 76650//1000//51147
// #define END   80000//76800//100000 //52843
#define START 0
#define END -1

//#define CORR_SIZE END-START
#define CORR_SIZE correlation_window_samples_num


#define FILENAME "data/r_pos.raw"


#define Z_SIZE 20

int main(){//int argc, char** argv) {
	Sampler sampler;

	CircularBuffer<audio_sample_t, CORR_SIZE> x1;
	CircularBuffer<audio_sample_t, CORR_SIZE> x2;


	CircularBuffer<int16_t, Z_SIZE> x1_z;
	CircularBuffer<int16_t, Z_SIZE> x2_z;

	CircularBuffer<int16_t, 2> x1_drv;
	CircularBuffer<int16_t, 2> x2_drv;

	DSP dsp;

	if(sampler.open(FILENAME) != 0){
		std::cerr << "ERROR starting sampler\n";
		return 1; 
	}

	std::vector<int> sig_n;
	std::vector<audio_sample_t> sig1;
	std::vector<audio_sample_t> sig2;

	std::vector<uint32_t> sig1_energy;
	std::vector<uint32_t> sig2_energy;

	std::vector<double> sig1_mean;
	std::vector<double> sig2_mean;

	std::vector<double> sig1_envelope;
	std::vector<double> sig2_envelope;
	
	std::vector<bool> sig1_onset;
	std::vector<bool> sig2_onset;

	int qq = 0;
	int count = 0;
	bool start_grab = false;
	double sum1 = 0;
	double sum2 = 0;
	sampler.sample([&](audio_sample_t left, audio_sample_t right) {   //x1, &x2, &dsp, &qq, &count, &sig_n, &sig1, &sig2
		int pos = (count++) + START;
		sig_n.push_back(pos);
		sig1.push_back(abs(left));
		sig2.push_back(abs(right));

		uint32_t left_energy = left*left;
		uint32_t right_energy = right*right;

		x1.push(left);
		x2.push(right);

		x1_drv.push(left);
		x2_drv.push(right);

		x1_z.push(abs(left));
		x2_z.push(abs(right));

		double x1_mean = x1_z.avg();
		double x2_mean = x2_z.avg();

		double x1_std = sqrt(x1_z.var(x1_mean));
		double x2_std = sqrt(x2_z.var(x2_mean));

		//printf("mean %f %f, std %f %f\n", x1_mean, x2_mean, x1_std, x2_std);
		

		sig1_energy.push_back(left_energy);
		sig2_energy.push_back(right_energy);

		sig1_mean.push_back(x1_mean);
		sig2_mean.push_back(x2_mean);

		double x1_e = x1_mean + x1_std; //pow(1*(sqrt(x1_mean) + pow(x1_std, 1/2)), 2);
		double x2_e = x2_mean + x2_std; //pow(1*(sqrt(x2_mean) + pow(x2_std, 1/2)), 2);
		double p = 0.2;
		sum1 = (p*abs(left)+sum1*(1-p))/2;
		sum2 = (p*abs(right)+sum2*(1-p))/2;
		sig1_envelope.push_back(sum1);
		sig2_envelope.push_back(sum2);
		//sig1_envelope.push_back(x1_drv[1]-x1_drv[0]);
		//sig2_envelope.push_back(x2_drv[1]-x2_drv[0]);
		//printf("MA %f %f\n", x1_MA.avg(), x1_MA.avg());

		bool detect = false;
		
		sig1_onset.push_back(sum1 > 500);
		sig2_onset.push_back(sum2 > 500);

		// if(left_energy > 30*left_energy_avg && right_energy > 30*right_energy_avg)
		// 	detect = true;

		if(sum1 > 500 && sum2>500) detect = true;

		// printf("%d, %d\n", left, right);
		// if(count%100 != 0) continue;
		// if(qq++ >= 512){
		// 	qq = 0;
		if(detect && start_grab == false){
			start_grab = true;
			printf("Start grab: %d\n", pos);
		}
		if(start_grab && ++qq >= CORR_SIZE){
			printf("Start processing: %d\n", pos);
			qq = 0;
			start_grab = false;
			if(pos == 319766 && false){
				sciplot::Plot2D plot_sig;
				plot_sig.xlabel("N");
				plot_sig.ylabel("val");
				plot_sig.drawCurve(sig_n, x1).label("#1_{value}");
				plot_sig.drawCurve(sig_n, x2).label("#2_{value}");

				std::pair<std::vector<int>, std::vector<double>> rk_biased = dsp.xcorr_complete<CircularBuffer<audio_sample_t, CORR_SIZE>>(x1, x2, CORR_SIZE, true);
				sciplot::Plot2D plot_corr_biased;
				plot_corr_biased.xlabel("k");
				plot_corr_biased.ylabel("Rx");
				plot_corr_biased.drawCurve(rk_biased.first, rk_biased.second).label("Rx_{biased}");
				
				std::pair<std::vector<int>, std::vector<double>> rk_unbiased = dsp.xcorr_complete<CircularBuffer<audio_sample_t, CORR_SIZE>>(x1, x2, CORR_SIZE, false);
				sciplot::Plot2D plot_corr_unbiased;
				plot_corr_unbiased.xlabel("k");
				plot_corr_unbiased.ylabel("Rx");
				plot_corr_unbiased.drawCurve(rk_unbiased.first, rk_unbiased.second).label("Rx_{unbiased}");
				
				sciplot::Figure fig = {{plot_sig}, {plot_corr_biased}, {plot_corr_unbiased}};	// Create figure to hold plot
				sciplot::Canvas canvas = {{fig}};	// Create canvas to hold figure

				// Show the plot in a pop-up window
				canvas.size(1000, 600);
				canvas.show();
			}
			//-----
			std::pair<int, double> xcorr_peak;
			bool xcorr_peak_found = dsp.xcorr_max<CircularBuffer<audio_sample_t, correlation_window_samples_num>>(x1, x2, xcorr_peak, correlation_window_samples_num, max_shift_samples_num+1, true);
			
			if(xcorr_peak_found){				
				double tau = xcorr_peak.first*(1./I2S_SAMPLE_RATE);
				int angle = dsp.rad2deg( acos((tau*sound_speed)/mics_distance) )+0.5;
				//char str[10];
				
				//sprintf(str, "%d", angle);
				printf("pos: %d, N: %d, max: %f, tau: %f s, angle: %d\n", pos, xcorr_peak.first, xcorr_peak.second, tau, angle);
			}
			
		}
	}, START, END);

	sampler.close();

	return 0;

	std::vector<int> ssn;
	std::vector<double> ssv;
	int N = CORR_SIZE;
	int max_k = N; //max_shift_samples_num+1;
	

	//double max_Rx = 0;
	//int max_Rx_pos = -1;
	for (int k = 0; k < max_k; k++) {
		int Rx_sum = 0;
		for (int n = 0; n < N - k; n++) {
			Rx_sum += x2[n] * x1[n + k];
		}
		double Rx_k = Rx_sum/N;// / (double)(N - k);
		ssn.push_back(k);
		ssv.push_back(Rx_k/2000);
		// if (Rx_k > max_Rx) {
		// 	max_Rx = Rx_k;
		// 	max_Rx_pos = k;
		// }
		// Serial.println(Rx_k);
	}
	
	/*
	std::cout << "x1 = [";
	for(unsigned int i = 0; i < x1.size(); i ++) printf("%d, ", x1[i]);
	std::cout << "];\n";

	std::cout << "x2 = [";
	for(unsigned int i = 0; i < x2.size(); i ++) printf("%d, ", x2[i]);
	std::cout << "];\n";
	*/

	// std::ofstream file;
	// file.open("/home/matej/Documents/FEL/5.semestr/TPS/Miniprojekt/assets/plots/DC_filtered_data.dat");
	// std::cout << "X1" << std::endl;
	// for(int i = 0; i < x1.size(); i ++) file << i << ',' << x1[i] << std::endl;
	// file.close();

	// Create a Plot object
	sciplot::Plot2D plot_signals;

	//plot.size(1000, 1000);

	// Set the font name and size
	//plot.fontName("Palatino");
	//plot.fontSize(12);

	// Set the x and y labels
	plot_signals.xlabel("N");
	plot_signals.ylabel("val");

	// Set some options for the legend
	// plot.legend()
	// 	.atOutsideBottom()
	// 	//.fontSize(10)
	// 	.displayHorizontal();
	// 	//.displayExpandWidthBy(2);
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

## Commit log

2022-10-27 working on schematic
    [AcousticDetection_HW.kicad_sch]
2022-11-05 add DC filter & testing correlation of signals
2023-01-22 sampler changed to .raw file support
2023-03-16 add 3D model of case for prototype
    [2D.dxf, AcousticDetectionCase.scad, AcousticDetectionCase.stl]
2023-03-18 add docs & flush=True for print
2023-03-19 add alive timer for SSE
2023-04-05 schematic update
    [AcousticDetection_HW.kicad_pcb, AcousticDetection_HW.kicad_sch]
2023-04-09 small fixes
    [AcousticDetection_HW.kicad_sch]
2023-04-09 working on pcb layout
    [AcousticDetection_HW.kicad_pcb]
2023-04-11 add POWER symbol for ERC & add parts links
    [AcousticDetection_HW.kicad_sch]
2023-04-11 fix pin types in symbols for ERC
2023-04-16 finishing pcb
    [AcousticDetection_HW.kicad_pcb, AcousticDetection_HW.kicad_sch]
2023-04-17 small changes
    [AcousticDetection_HW.kicad_pcb]
2023-04-17 parts labels reposition
    [AcousticDetection_HW.kicad_pcb]
2023-04-18 pcb fabrication
    [AcousticDetection_HW-B_Cu.gbl, AcousticDetection_HW-B_Mask.gbs, AcousticDetection_HW-B_Paste.gbp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]
2023-04-18 add separated parts
    [part1-B_Cu.gbl, part1-B_Mask.gbs, part1-B_Paste.gbp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]
2023-04-18 all parts on a single board
    [AcousticDetection_HW-B_Cu.gbl, AcousticDetection_HW-B_Mask.gbs, AcousticDetection_HW-B_Paste.gbp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]
2023-05-08 the resistor values of pcb leds were changed to 220R
    [AcousticDetection_HW.kicad_pcb, AcousticDetection_HW.kicad_sch]
2023-05-21 add version for 3D export and models
    [AcousticDetection_HW_ForModel.kicad_pcb, AcousticDetection_HW_ForModel.kicad_sch]
2023-05-21 add title
    [AcousticDetection_HW.kicad_pcb]
2023-05-21 schematic cleanup
    [AcousticDetection_HW.kicad_sch]
2023-05-21 add schematic plot
2023-05-21 add pcb pdf export
2023-05-23 changed mics distance to 0.2m (new board)
2023-05-23 add angle error & variable barpolar width into UI
    [main.cpp]
2023-06-12 add case for the final device
    [2D.dxf, AcousticDetectionCase.scad, AcousticDetectionCase.stl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]
2023-07-15 changed arms screw holders outer diameter & add usb-c soldering holes
    [2D.dxf]
2023-07-17 case improvements
    [2D.dxf, AcousticDetectionCase.scad, AcousticDetectionCase.stl]
